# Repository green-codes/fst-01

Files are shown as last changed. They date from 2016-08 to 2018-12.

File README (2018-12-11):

Flying Stone Tiny 01 (FST-01SZ) PCB Design

							   Version 3.01
							     2018-12-11
						           Niibe Yutaka
						Flying Stone Technology

What's FST-01?
==============

Flying Stone Tiny 01 (FST-01) is a USB 32-bit computer by STM32 or
GD32 processor.  It has minimalist design.  It is composed by MCU
running at 72MHz or 108MHz, LED to notify a user, a hall effect sensor
for user input, and SWD port for main flash ROM update.  That's all.

This is designed mainly for our own projects: Gnuk and NeuG.

FST-01SZ is the third revision, integrating feedback from users.

MCU is new one from China.  Instead of offering extension I/O,
fixed-purpose sensor is added.  Optional flash memory is removed.

Please note that the format of KiCAD has been changed (again).

These files are for what?
=========================

This is FST-01 PCB design for KiCAD.

I am using kicad of 5.0.1+dfsg1-3 in Debian.

Files
=====

    README:      This file
    ChangeLog:   History of this project
    fst-01.pro:  Project file of KiCAD
    fst-01.sch:  Schematic
    fst-01.net:  Netlist
    fst-01.xml:  Component and Module
    fst-01.kicad_pcb:  PCB design
    library: schematic library
    module.pretty: footprint modules for PCB

    datasheet:   Datasheets of parts

Note that files under datasheet directory is copyrighted by vendors.

Terms and conditions
====================

FST-01 is my work, but I am not sure how and what I can demand for
users.  I think that PCB design and files can be copyrighted.

I assume that users don't use verbatim copy of this design.  It
includes my trade marks of "FST-01SZ" and Flying Stone logo.  Please
just don't include silk bottom layer, if you build your own PCB.

I would like to ask users to keep the design as "Open Hardware".  See
the archived page for the definition of "Open Hardware":

    https://web.archive.org/web/20140407171518/http://www.opencollector.org/Whyfree/open_hardware.html

That is, interface, design itself, and tools for the design should be
free.  Tools should be Free Software, in my opinion.  It is not enough
if tools are available by download with no cost.  Source code of tools
should be available and modification can be permitted.

Nevertheless, schematic design is distributed under the Creative
Commons Attribution 4.0 International License (CC BY 4.0).  See:

    https://creativecommons.org/licenses/by/4.0/

Schematic design can be used for any purpose and you don't need to
publish your modifications over my design.

For PCB, it is distributed under the Creative Commons
Attribution-ShareAlike 3.0 Unported (CC BY-SA 3.0).  See:

    https://creativecommons.org/licenses/by-sa/3.0/

External modules
================

The modules of module.pretty/c_0402.kicad_mod and
module.pretty/c_0603.kicad_mod was the one in the original file name
of module/SMT_CAP.mod in the version 1.00 of FST-01.

The module of module.pretty/r_0402.kicad_mod was module/SMT_RES.mod
in the version 1.00 of FST-01.

Those module drawings are copied from w_smd_cap.mod and
w_smd_resistors.mod by W.Lain.  Files were downloaded from:

   http://smisioto.no-ip.org/elettronica/kicad/kicad-en.htm

Its copyright notice is like following:
---------------------------------------------------------------------
Kicad Library by W. Lain - kcswalter@member.fsf.org

This library is released under the terms of the Creative Commons
license v3.0, Attribution-Share Alike.

The author holds no responsibility for any damage that can be caused
by the usage of this library. You are however welcome to report any
error or discrepance to the author, provided that you give also the
correct information and its source (i.e. the correct datasheet).

Note that the author used publicly available data sheets from many
different companies, and that package dimensions, pin numeration and
schematic symbols may vary slightly between companies.
---------------------------------------------------------------------
--

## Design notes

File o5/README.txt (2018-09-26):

README.txt: This file

BOM: BOM-fst-01sz.csv

For PCB:
	Top copper: FST-01SZ.GTL
	Top soldermask: FST-01SZ.GTS
	Top silkscreen: FST-01SZ.GTO
	Bottom copper: FST-01SZ.GBL
	Bottom soldermask: FST-01SZ.GBS
	Botom silkscreen: FST-01SZ.GBO
	Board Outline: FST-01SZ.GML
	Drills: FST-01SZ.TXT

For PCBA:

	Component Placement File: FST-01SZ-placement.CSV
	Top solderpaste: FST-01SZ.GTP
	How parts are placed: FST-01SZ-Dwgs.pdf

For parts which is not OPL, here are more information.

(1) GD32F103TBU6

    Giga Device 
    http://www.gigadevice.com/products/microcontrollers/gd32/arm-cortex-m3/mainstream-line/gd32f103-series/gd32f103tbu6/

    Possible suppliers:
    深圳市瑞江无限科技有限公司
    https://detail.1688.com/offer/573169039590.html

    深圳市铭顺信电子有限公司
    https://detail.1688.com/offer/568527808820.html

(2) ZL-272

    USB_A 手腕主体2.0
    广东中连精密工业有限公司, ShenZhen, China
    http://www.usbljq.com/m/?/goods/id-403/index.html

    Possible suppliers:
    广东中连精密工业有限公司
    https://detail.1688.com/offer/566273410945.html

    深圳市光明新区公明三杰盛电子经营部 
    https://detail.1688.com/offer/568913556657.html

(3) MCP1700-3302E/TT

https://www.digikey.com/product-detail/en/microchip-technology/MCP1700T-3302E-TT/MCP1700T3302ETTCT-ND/652677
--

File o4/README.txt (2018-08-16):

README.txt: This file

BOM: BOM-fst-01sz.csv

For PCB:
	Top copper: FST-01SZ.GTL
	Top soldermask: FST-01SZ.GTS
	Top silkscreen: FST-01SZ.GTO
	Bottom copper: FST-01SZ.GBL
	Bottom soldermask: FST-01SZ.GBS
	Botom silkscreen: FST-01SZ.GBO
	Board Outline: FST-01SZ.GML
	Drills: FST-01SZ.TXT

For PCBA:

	Component Placement File: FST-01SZ-placement.CSV
	Top solderpaste: FST-01SZ.GTP
	How parts are placed: FST-01SZ-Dwgs.pdf

For parts which is not OPL, here are more information.

    GD32F103TBU6:
    Giga Device 
    http://www.gigadevice.com/products/microcontrollers/gd32/arm-cortex-m3/mainstream-line/gd32f103-series/gd32f103tbu6/

    Possible suppliers:
    https://item.taobao.com/item.htm?spm=a230r.1.14.27.37b72ca1EsXZ8H&id=562055310947&ns=1&abbucket=16#detail
    https://item.taobao.com/item.htm?spm=a230r.1.14.16.37b72ca1EsXZ8H&id=553714950588&ns=1&abbucket=16#detail

The part for the connector J1 is an option.

    ZL-272:
    "USB_A 手腕主体2.0","广东中连精密工业有限公司, ShenZhen, China"
    http://www.usbljq.com/

    Possible supplier:
    https://detail.1688.com/offer/568913556657.html?spm=a261b.2187593.0.0.63e01de6NhfCCV

Since I will solder ZL-272 by myself, don't need for this PCBA request.
--

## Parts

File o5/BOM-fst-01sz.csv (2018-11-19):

Designator | Manufacturer Part Number | Quantity | Spec. | Comment
U2 | MCP1700-3302E/TT | 1 | LDO, 3.3V, SOT23 | Microchip
U4 | DRV5032FA | 1 | Hall Effect Sensor, X2SON | Texas Instruments
U1 | GD32F103TBU6 | 1 | QFN36 | Giga Device
J1 | ZL-272 | 1 | USB A 手腕主体2.0 | 广东中连精密工业有限公司, ShenZhen, China
U3 | NUF2221W1T2G | 1 | SOT363 | ON Semiconductor
X1 | Epson;FA-20H 12MHz | 1 | 12MHz | OPL
D1 | 19-217-BHC-ZL1M2RY-3T | 1 | LED Blue, Vf=2.5-3.1V, 0603 | OPL
R1 | RC0402FR-07470RL | 1 | 470R, 0402 | OPL
C6,C7 | CC0603KRX5R6BB475 | 2 | 4.7uF, 0603, 10V | OPL
C1,C2,C3,C4,C5 | CC0402KRX5R6BB104 | 5 | 0.1uF, 0402, 10V | OPL

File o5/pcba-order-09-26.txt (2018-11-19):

Order 	Location 	MPN/SKU 	Quantity 	Waste Qty 	Amount 	Status
1 	U2		MCP1700-3302E/TT 	1 * 10 	0 	$5.00 	Confirmed
2 	U4		DRV5032FADMRR 	1 * 10 	1 	$7.48 	Confirmed
3 	U1		GD32F103TBU6 	1 * 10 	0 	$15.00 	Confirmed
4 	J1		ZL-272 	1 * 10 	1 	$1.10 	Confirmed
5 	X1		306010127 	1 * 10 	1 	$1.43 	Confirmed
6 	D1		304090045 	1 * 10 	2 	$0.12 	Confirmed
7 	R1		301010012 	1 * 10 	5 	$0.15 	Confirmed
8 	C6,C7		302010111 	2 * 10 	5 	$0.25 	Confirmed
9 	C1,C2,C3,C4,C5	302010037 	5 * 10 	10 	? 	Confirmed
10 	U3		NUF2221W1T2G 	1 * 10	1 	$4.75

================= From web order, which was wrong for C1...C5 and missing U3
BOM

    Total parts:9
    Confirmed:9

Order 	Location 	MPN/SKU 	Quantity 	Waste Qty 	Amount 	Status
1 	U2		MCP1700-3302E/TT 	1 * 10 	0 	$5.00 	Confirmed
2 	U4		DRV5032FADMRR 	1 * 10 	1 	$7.48 	Confirmed
3 	U1		GD32F103TBU6 	1 * 10 	0 	$15.00 	Confirmed
4 	J1		ZL-272 	1 * 10 	1 	$1.10 	Confirmed
5 	X1		306010127 	1 * 10 	1 	$1.43 	Confirmed
6 	D1		304090045 	1 * 10 	2 	$0.12 	Confirmed
7 	R1		301010012 	1 * 10 	5 	$0.15 	Confirmed
8 	C6,C7		302010111 	2 * 10 	5 	$0.25 	Confirmed
9 	C1,C2,C3,C4,C5	302010004 	5 * 10 	10 	$6.00 	Confirmed

Missing, should be added.

10 	U3		NUF2221W1T2G 	1 * 10	 	1 		$4.75

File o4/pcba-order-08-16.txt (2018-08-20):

BOM

    Total parts:9
    Confirmed:9

Order 	Location 	MPN/SKU 	Quantity 	Waste Qty 	Amount 	Status
1 	R1		301012000 	1 * 10	 	5 		$0.17 	Confirmed
2 	C1,C2,C3,C4,C5	302010037 	5 * 10 		10 		$0.90 	Confirmed
3 	C6,C7		302010111 	2 * 10	 	5 		$0.45 	Confirmed
4 	X1		306010127 	1 * 10	 	1 		$1.43 	Confirmed
5 	D1		304090045 	1 * 10	 	2 		$0.72 	Confirmed
6 	U1		GD32F103TB 	1 * 10	 	1 		$38.37 	Confirmed
7 	U2		MCP1700-3302E/TO	1 * 10 	1 		$4.34 	Confirmed
8 	U3		NUF2221W1T2G 	1 * 10	 	1 		$4.75 	Confirmed
9 	U4		DRV5032FADMRR 	1 * 10	 	1 		$7.43 	Confirmed

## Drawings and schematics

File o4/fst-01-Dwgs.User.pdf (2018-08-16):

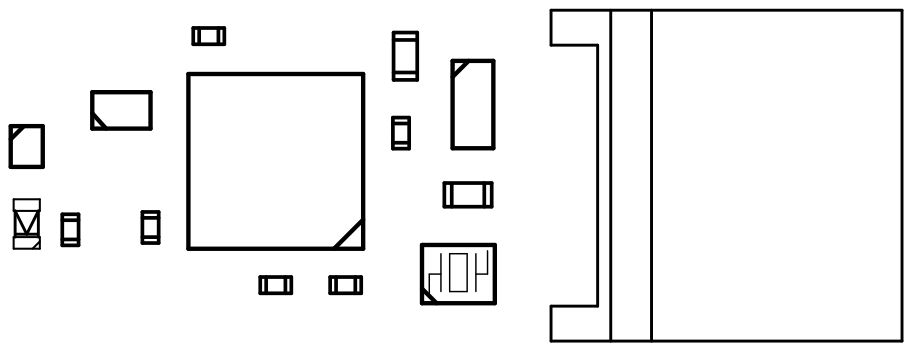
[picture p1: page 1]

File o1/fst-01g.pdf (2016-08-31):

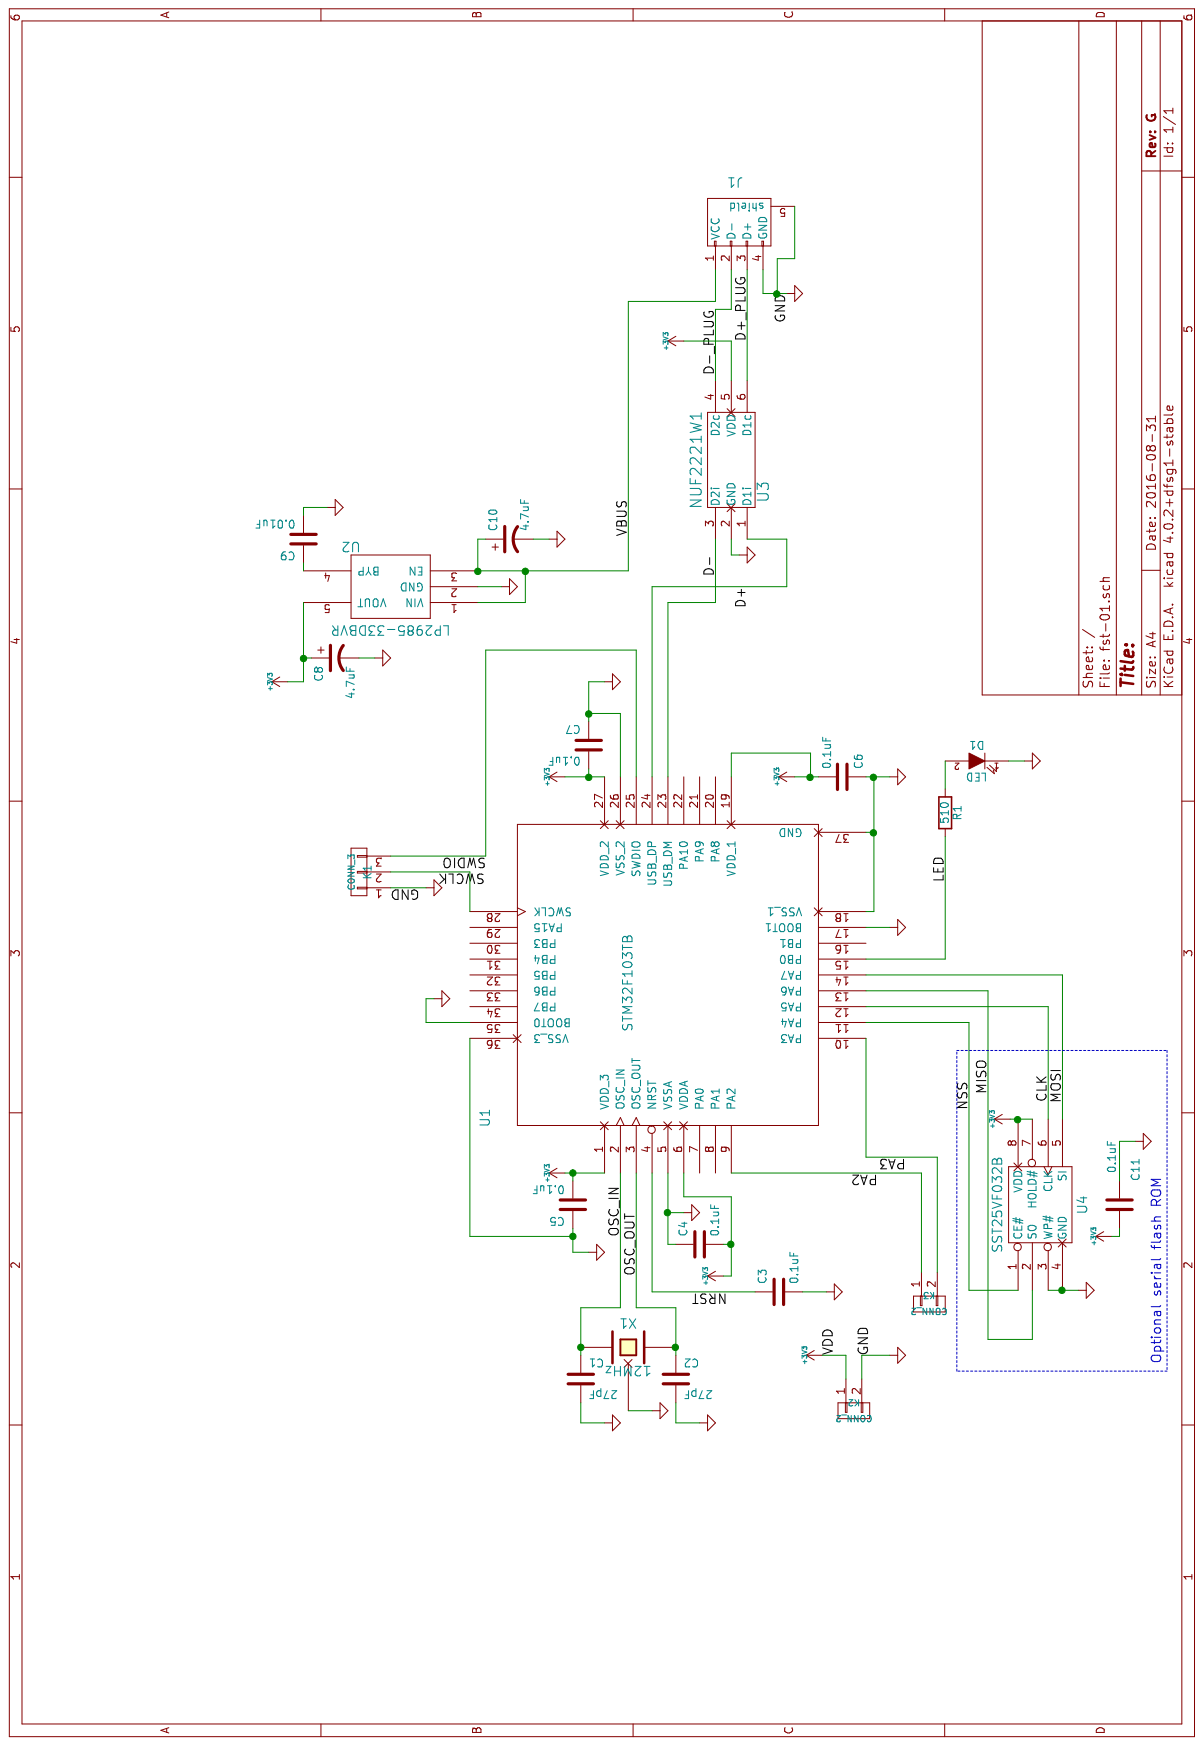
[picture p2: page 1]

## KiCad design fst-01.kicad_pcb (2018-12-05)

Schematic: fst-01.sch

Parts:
C1, C2, C3, C4, C5: 0.1uF; c_0402
C6, C7: 4.7uF; c_0603
D1: LED; LED0603
J1: USB_A; USB-A-ZT01
K1: CONN_5; SIL-5
R1: 470; r_0402
U1: GD32F103TB; QFN36
U2: MCP1700-3302E; SOT-23
U3: NUF2221W1; SOT363
U4: DRV5032FA; X2SON
X1: 12MHz; FA-20H

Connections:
+3V3: C1.2, C2.2, C4.2, C5.2, C6.1, K1.1, U1.1, U1.6, U1.19, U1.27, U2.2, U3.5, U4.1
/D+: U1.24, U3.1
/D+_PLUG: J1.3 (D+), U3.6
/D-: U1.23, U3.3
/D-_PLUG: J1.2 (D-), U3.4
/LED: D1.2 (A), U1.20
/NRST: C3.1, K1.4, U1.4
/OSC_IN: U1.2, X1.1
/OSC_OUT: U1.3, X1.2
/PA3: U1.10, U4.4
/SWCLK: K1.3, U1.28
/SWDIO: K1.2, U1.25
/VBUS: C7.1, J1.1 (VCC), U2.3
GND: C1.1, C2.1, C3.2, C4.1, C5.1, C6.2, C7.2, J1.4 (GND), J1.5 (shield), K1.5, R1.2, U1.5, U1.17, U1.18, U1.26, U1.35, U1.36, U1.37, U2.1, U3.2, U4.2, X1.3
unnamed: D1.1 (K), R1.1

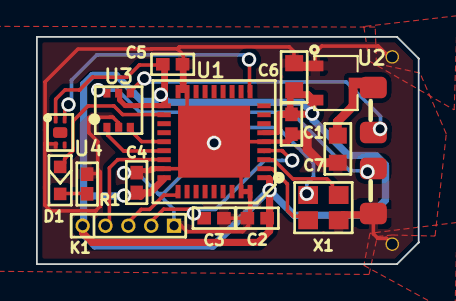
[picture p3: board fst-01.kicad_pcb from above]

Board: 2 copper layers, 21.2 x 12.6 mm, 17 parts (1 on the bottom side), 15 nets.

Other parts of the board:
FST-LOGO: VAL**; FST-LOGO

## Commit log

2011-08-08 Start using KiCAD
    [fst-01.sch]
2011-08-08 Start drawing
    [fst-01.brd]
2011-08-09 draw PCB outline 13.5mm x 26mm
    [fst-01.brd]
2011-08-10 Connect LED and R1
    [fst-01.sch]
2011-08-10 Connect wires, fill zones
    [fst-01.brd]
2011-08-10 Move references and values. Draw logo and product number.
    [fst-01.brd]
2011-08-10 set plot parameters
    [fst-01.brd]
2011-08-19 fix STF-202 connection
    [fst-01.brd, fst-01.sch]
2011-08-22 fix logo
    [fst-01.brd]
2011-08-23 Use NUF2221 instead of STF202
    [fst-01.brd, fst-01.sch]
2011-08-26 move silks for references
    [fst-01.brd]
2011-08-26 move silks for references (2)
    [fst-01.brd]
2011-08-26 change silk of LED
    [fst-01.brd]
2011-08-26 change capacitor module
    [fst-01.brd]
2011-08-26 change resistor module
    [fst-01.brd]
2011-08-26 change TSOT23-5 module
    [fst-01.brd]
2011-08-26 change TSOT23-5 module (2)
    [fst-01.brd]
2011-09-05 Fix NUF2221 connection
    [fst-01.brd, fst-01.sch]
2011-09-06 minor change for silk
    [fst-01.brd]
2011-09-06 fix Reference U3 size and position
    [fst-01.brd]
2011-09-08 Pads Mask Clearance
    [fst-01.brd]
2011-09-08 silk improvement
    [fst-01.brd]
2011-09-09 Major change: QFN36
    [fst-01.brd, fst-01.sch]
2011-09-12 improve small things
    [fst-01.brd]
2011-09-12 QFN 37 pin solder paste improvement
    [fst-01.brd]
2011-09-30 Change for SPI flash memory and small XTAL
    [eco2-pcb-outline.brd, fst-01.brd, fst-01.sch]
2011-10-19 improvement a bit
    [fst-01.brd]
2011-10-20 update PCB
    [fst-01.brd]
2016-06-08 board size change
    [fst-01.brd]
2016-08-29 change +3V3 part in schematic.
    [fst-01.sch]
2016-08-29 change parts of connectors
    [fst-01.sch]
2016-08-29 fix connections of schematic
    [fst-01.sch]
2016-08-29 fix direction of LED of schematic
    [fst-01.sch]
2016-08-29 Fix schematic to FST-01G.
    * Make Serial flash ROM optional.
    * Connect USB connector's shield to GND.
    * Remove USB_EN control.
    [fst-01.sch]
2016-08-29 change LDO to LP2985-33
    [fst-01.sch]
2016-08-31 Add a footprint for newer KiCAD
2016-08-31 migrate footprint to newer KiCAD
2016-08-31 Fix LED direction
2016-08-31 add missing SOT363 footprint
2016-08-31 Fix footprints
2016-08-31 Update sch and net
    [fst-01.sch]
2016-08-31 Update footprints
2016-08-31 Remove old files for older KiCAD
2016-08-31 Remove old footprints
2016-08-31 Add smd attr to footprint to generate POS
2016-08-31 fix U1 and U2
    [fst-01.kicad_pcb]
2016-08-31 update date
    [fst-01.sch]
2016-08-31 Add WEEE-Logo from github/KiCad
2016-08-31 Add WEEE-logo
    [fst-01.kicad_pcb]
2016-08-31 Add generated files for the first version of FST-01G
    [bom-fst-01.csv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]
2018-08-08 More change.
    [fst-01.kicad_pcb, fst-01.sch]
2018-08-08 Add hole sensor, drv5032.
    [fst-01.kicad_pcb, fst-01.sch]
2018-08-09 More change to PCBA.
    [fst-01-B.Mask.gbs, fst-01-B.Paste.gbp, fst-01-B.SilkS.gbo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]
2018-08-10 More changes.
    [fst-01-B.Mask.gbs, fst-01-B.Paste.gbp, fst-01-B.SilkS.gbo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]
2018-08-10 Add ordered files (including *.zip).
    [FST-01SZ.GBL, FST-01SZ.GBO, FST-01SZ.GBS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]
2018-08-11 change parts.
    [fst-01.kicad_pcb, fst-01.sch]
2018-08-11 Ask PCBA quote with this.
    [bom-fst-01sz.csv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]
2018-08-13 Add position file and name change for U1 to GD.
    [fst-01.kicad_pcb, fst-01.sch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]
2018-08-13 Add files for PCBA.
    [FST-01SZ.CSV]
2018-08-16 Update PCBA.
    [BOM-fst-01sz.csv, FST-01SZ-placement.CSV, FST-01SZ.CSV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]
2018-08-16 Update for the order of PCBA.
    [BOM-fst-01sz-with-J1.csv, BOM-fst-01sz-with-no-J1.csv]
2018-08-16 Solder paste for J1 holes to be used to position stencil.
    [FST-01SZ.GTP, fst-01-B.Mask.gbs, fst-01-B.Paste.gbp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]
2018-08-20 Shape of PCB modified.
    [FST-01SZ-manual-stencil.GTP, FST-01SZ.GBL, FST-01SZ.GBO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]
2018-09-25 Save Aug 16 order to o4.
    [BOM-fst-01sz-with-J1.csv, BOM-fst-01sz-with-no-J1.csv, FST-01SZ-placement.CSV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]
2018-09-26 Order of 2018-09-26.
    [fst-01-B.Mask.gbs, fst-01-B.Paste.gbp, fst-01-B.SilkS.gbo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]
2018-09-26 Update just before the order.
    [BOM-fst-01sz.csv, FST-01SZ-placement.CSV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]
2018-09-26 More change to order.
    [BOM-fst-01sz.csv]
2018-11-19 Add info for BOM and order to fusion PCBA service on September 26.
    [BOM-fst-01sz.csv]
2018-12-04 Fix holes for J1 (distance is 10.40mm).
    [fst-01.kicad_pcb]
2018-12-05 Move output to o5.
    [BOM-fst-01sz.csv, FST-01SZ-placement.CSV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]
2018-12-05 Fix J1 outlines.
    [fst-01.kicad_pcb]
2018-12-05 Add GND lines to central heat-pad.
    [fst-01.kicad_pcb]
2018-12-05 Add updated output/.
    [BOM-fst-01sz.csv, FST-01SZ-placement.CSV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]
